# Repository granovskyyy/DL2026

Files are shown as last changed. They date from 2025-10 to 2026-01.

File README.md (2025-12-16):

# DL2026
Design Lab classes repository 
Project - IoT system based on ATMega328PB with all connectivity interfaces (I2C, SPI, UART etc) 
### FEATURES
The projects support various connectivity protocols such as: 
- UART
- I2C
- SPI
- 1-WIRE
- Outputs (7seg display)  
Software functions:
- UART connectivity and displaying counter of 7-seg display as well as data obtained from the sensors.
### HARDWARE
- ATMega328PB - microcontroller  
- BMP280 - Pressure sensor 
- DS18B20 – temperature probe 
- PL2303 - UART connectivity (in schematic is FT232RL used due to KiCad avaibality) 
- 3.3V voltage regulators 
- Capacitors (100n ceramic and 10uF electrolytic) 
- Resistors (4,7K to pullup, 220 for 7seg)
### SCHEMATIC


### PCB LAYOUT


### PCB MODEL


### PROJECT STRUCTURES  
- /datasheets/-  Components datasheets 
- schematics/  -  Schematics and PCB designs 
- I2C-BMP280/  -  I2C examples with BMP280 
- Final Project – complete DL code with support for all protocols 
- README.md

### SOFTWARE
- KiCad
- AVR Microchip Studio
#### COMPILATION 
avr-gcc -mmcu=atmega328pb -Os -o main.elf source_file.c
avr-objcopy -O ihex main.elf main.hex
#### FLASH
avrdude -c usbasp -p m328pb -U flash:w:main.hex

NOTE- you can compile code via Makefile

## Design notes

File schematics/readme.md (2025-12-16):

KICad is required to open schematics

This custom circuit was designed to measure properties of the fluids or gases using sensors, which could be obtained by connecting to the board via USB to uart connection or serial port.

Overall structure of the project is:
    -> datasheets folder - contains datasheets of all the elements used in the project.
    It is: 
        sensors: 
            BMP280, 
            BS18B20, 
        usb to uart: 
            PL2303GS USB to Full UART IC, 
        ATmega328PB Xplained Mini board.
    -> I2C-BMP280 folder - containing base library of communicating with BMP280 sensors via I2C interface, which was helpful in process of writing custom firmware for the project case.
    -> schematics folder - containing Electric Schematic and PCB design of the circuit.
    -> Final Project folder - containing final versions of the software used to read and display the data from sensors.

Firmware was written in C to maintain high readability, modularity and speed of the code, as well as future development of the project.

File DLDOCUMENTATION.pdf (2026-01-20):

# AGH UNIVERSITY OF CRACOW

# Project documentation - Design Lab 2025

### Authors: Karol Ożga, Tomasz Granowski, Dawid Chmielewski

## 1. Project description

This repository contains laboratory and final project work created during Design Lab classes. The project focuses on building an embedded IoT system using the ATMega328PB microcontroller and multiple communication interfaces.

## 2. Features:

The projects support various connectivity protocols such as:

- UART
- I2C
- SPI
- 1-WIRE
- Outputs (7seg display)

Software functions

- UART connectivity and displaying counter of 7-seg display as well as data obtained from the sensors.

## 3. Hardware:

- ATMega328PB - microcontroller
- BMP280 - Pressure sensor
- DS18B20 – temperature probe
- PL2303 - UART connectivity
- 3.3V voltage stabilizators
- Capacitors (100n ceramic and 10uF electrolyphic)
- Resistors (4,7K to pullup, 220 for 7seg)

## 4. Schematics:

Schematic:

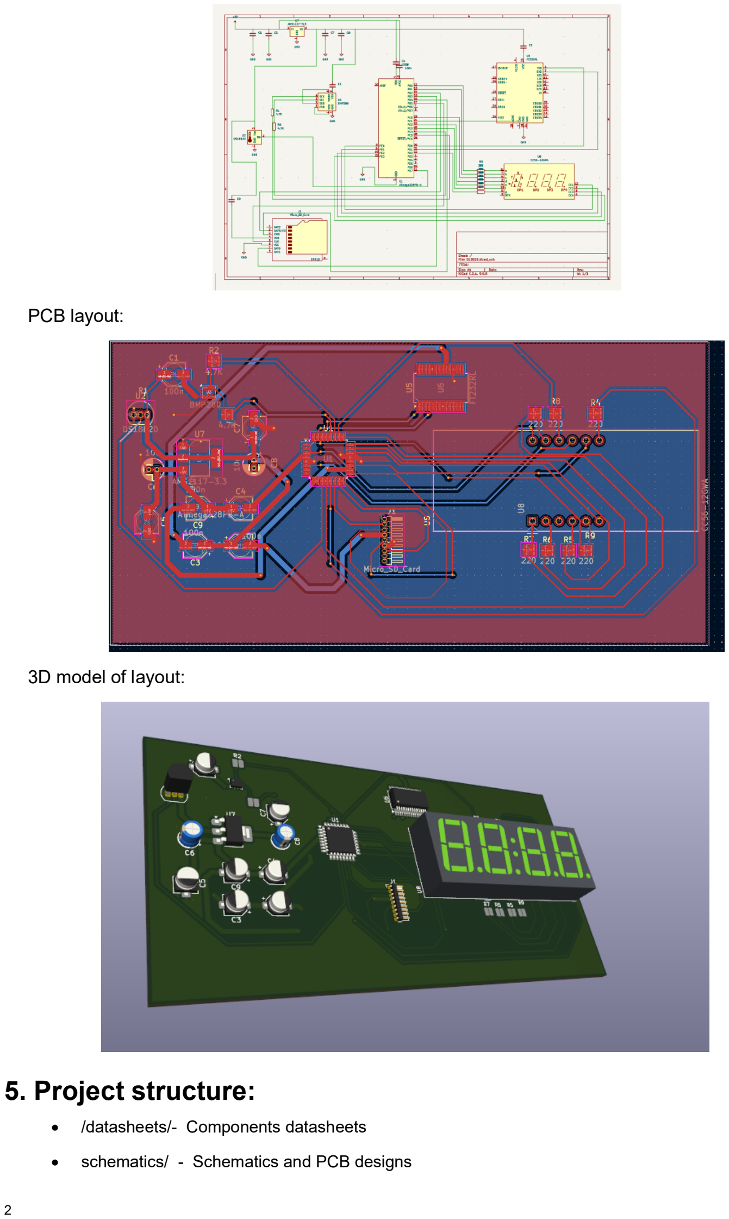
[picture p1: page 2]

2

PCB layout:

3D model of layout:

## 5. Project structure:

- /datasheets/- Components datasheets
- schematics/ - Schematics and PCB designs

3

- I2C-BMP280/ - I2C examples with BMP280
- Final Project – complete DL code with support for all protocols
- README.md

## 6. Requiremets

KiCad is required to open the schematics.

To build and run firmware you need:

- Software to program ATMega like AVR Microchip studio
- AVR_GCC toolchain
- “avr/io.h” , “util/delay.h” , “stdint.h” , “avr/interrupt.h” libraries
- If you want to compile project via terminal use these commands:

avr-gcc -mmcu=atmega328pb -Os -o main.elf source_file.c

avr-objcopy -O ihex main.elf main.hex

To flash use:

- avrdude -c usbasp -p m328pb -U flash:w:main.hex

Change settings/filenames if needed.

## 7. Connectivity with board

Data can be obtained via USB to Uart converter or via serial port. The circuit sends data which can be saved and later analyzed.

## 8. Possible Future improvements

Include saving data on SD card via SD card reader. Developing connectivity with the board via Bluetooth or Wi-Fi module. Creating a pc/mobile/web app displaying the measurements and options to save the data.

## 9. Links/sources

GitHub - https://github.com/granovskyyy/DL2026

## 10. Notes

This project is for educational purposes only.

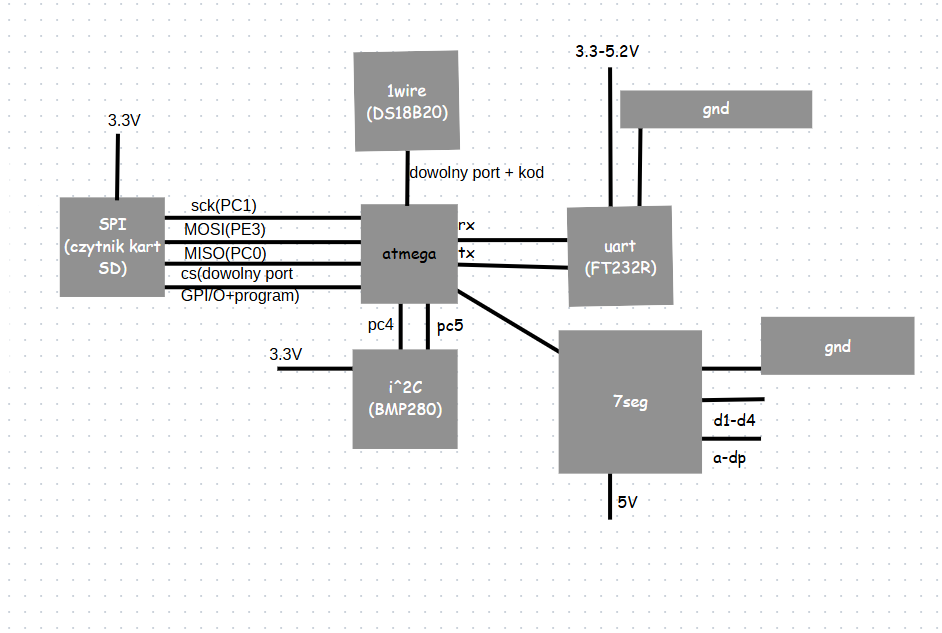
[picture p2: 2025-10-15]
schematics/Zrzut ekranu 2025-10-15 213119.png

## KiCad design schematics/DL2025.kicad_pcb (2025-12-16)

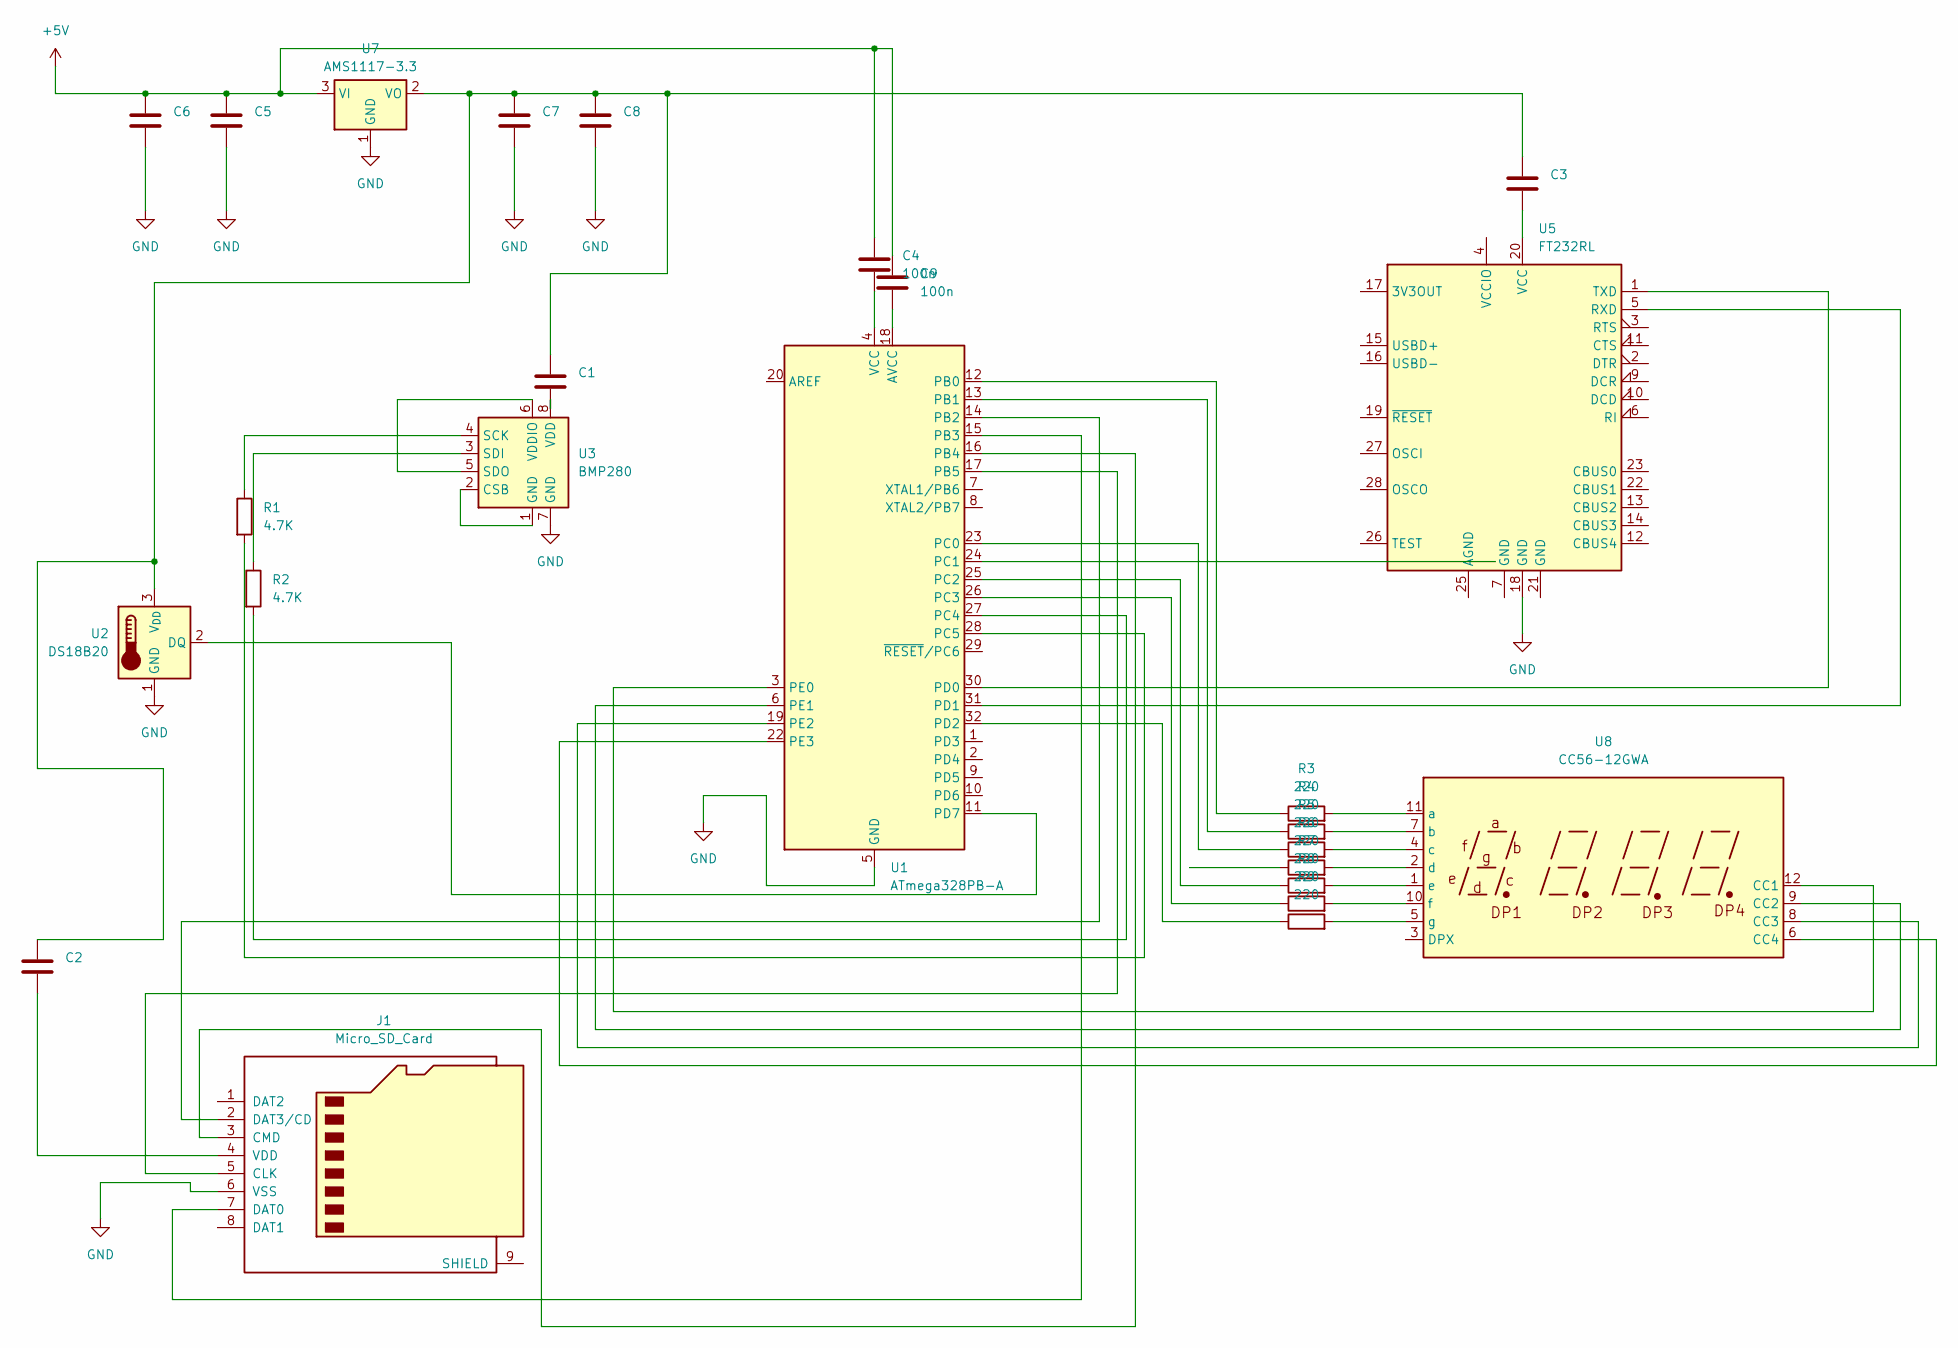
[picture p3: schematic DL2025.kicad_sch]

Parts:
C1, C2, C3, C4, C5, C7, C9: 100n; CP_Elec_4x3
C6, C8: 10u; CP_Radial_D4.0mm_P1.50mm
J1: Micro_SD_Card; PinHeader_1x09_P1.00mm_Horizontal
R1, R2: 4.7K; R_0508_1220Metric_Pad1.12x2.15mm_HandSolder
R3, R4, R5, R6, R7, R8, R9: 220; R_0508_1220Metric_Pad1.12x2.15mm_HandSolder
U1: ATmega328PB-A; TQFP-32_7x7mm_P0.8mm
U2: DS18B20; TO-92_Inline
U3: BMP280; Bosch_LGA-8_2x2.5mm_P0.65mm_ClockwisePinNumbering
U5: FT232RL; SSOP-28_5.3x10.2mm_P0.65mm
U7: AMS1117-3.3; SOT-223-3_TabPin2
U8: CC56-12GWA

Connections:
+5V: C4.1, C5.1, C6.1, C9.1, U7.3 (VI)
GND: C5.2, C6.2, C7.2, C8.2, J1.6 (VSS), U1.5 (GND), U1.21 (GND), U2.1 (GND), U3.7 (GND), U5.18 (GND), U7.1 (GND)
unnamed: J1.5 (CLK), U1.17 (PB5)
unnamed: J1.3 (CMD), U1.16 (PB4)
unnamed: J1.7 (DAT0), U1.15 (PB3)
unnamed: J1.2 (DAT3/CD), U1.14 (PB2)
unnamed: C2.2, J1.4 (VDD)
unnamed: C9.2, U1.18 (AVCC)
unnamed: R3.1, U1.12 (PB0)
unnamed: R4.1, U1.13 (PB1)
unnamed: R5.1, U1.23 (PC0)
unnamed: R6.1, U1.24 (PC1)
unnamed: R7.1, U1.25 (PC2)
unnamed: R8.1, U1.26 (PC3)
unnamed: R2.2, U1.27 (PC4)
unnamed: R1.2, U1.28 (PC5)
unnamed: U1.30 (PD0), U5.1 (TXD)
unnamed: U1.31 (PD1), U5.5 (RXD)
unnamed: R9.1, U1.32 (PD2)
unnamed: U1.11 (PD7), U2.2 (DQ)
unnamed: U1.3 (PE0), U8.12 (CC1)
unnamed: U1.6 (PE1), U8.9 (CC2)
unnamed: U1.19 (PE2), U8.8 (CC3)
unnamed: U1.22 (PE3), U8.6 (CC4)
unnamed: C4.2, U1.4 (VCC)
unnamed: C1.1, C2.1, C3.1, C7.1, C8.1, U2.3 (V_{DD}), U7.2 (VO)
unnamed: U3.1 (GND), U3.2 (CSB)
unnamed: R1.1, U3.4 (SCK)
unnamed: R2.1, U3.3 (SDI)
unnamed: U3.5 (SDO), U3.6 (VDDIO)
unnamed: C1.2, U3.8 (VDD)
unnamed: C3.2, U5.20 (VCC)
unnamed: R3.2, U8.11 (a)
unnamed: R4.2, U8.7 (b)
unnamed: R5.2, U8.4 (c)
unnamed: R6.2, U8.2 (d)
unnamed: R7.2, U8.1 (e)
unnamed: R8.2, U8.10 (f)
unnamed: R9.2, U8.5 (g)

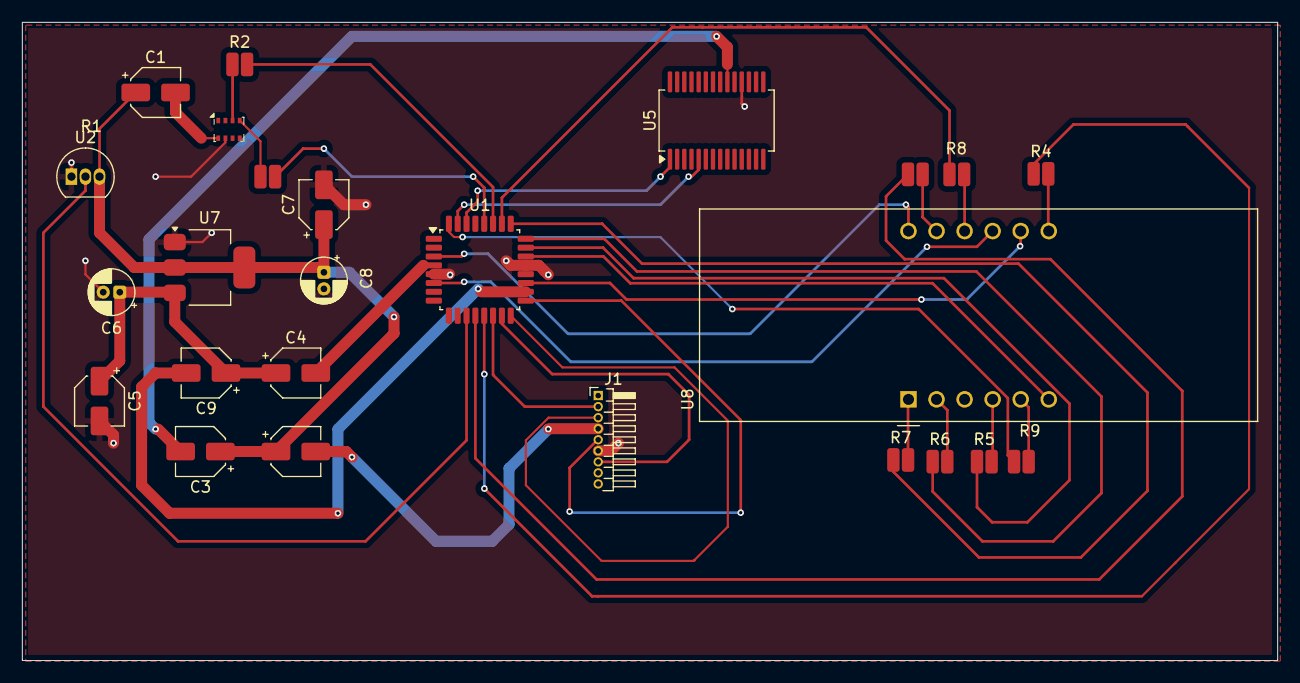
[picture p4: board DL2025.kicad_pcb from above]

Board: 2 copper layers, 113.7 x 57.8 mm, 25 parts (0 on the bottom side), 39 nets.

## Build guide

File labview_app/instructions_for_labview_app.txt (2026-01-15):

1. Na płytce wgrany jest nowy soft (nowy plik main.cpp) reszta taka sama.
2. Podłączasz płytkę przez usb, szukasz na którym COMx porcie jest.
3. W labview na front panelu wybierz VISA resource name -> COMx płytki
4. Aby zacząć odczytywać dane zakładka OPERATE -> RUN

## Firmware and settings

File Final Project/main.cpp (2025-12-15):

#define F_CPU 16000000UL

#include <avr/io.h>
#include <util/delay.h>
#include <stdint.h>
#include <avr/interrupt.h>
#include "uart.h"
#include "I2C.h"
#include "BMP280.h"
#include "DS18B20.h"
#include "7SEG.h"
#include "button.h"


int main(void)
{
	// output LEDs
	DDRB |= (1 << PB2) | (1 << PB3) | (1 << PB4);
	PORTB &= ~((1 << PB2) | (1 << PB3) | (1 << PB4)); // turn off all LEDs

	uart_init(9600);
	i2c_init();
	display_io_init();
	display_timer_init();
	button_init();
	ds18b20_io_init();

	sei(); // enable global interrupts (for display timer)

	uart_puts("\r\nBMP280 + DS18B20 temp + pressure with 7-seg display\r\n");
	bmp280_init();

	int32_t adc_T = 0, adc_P = 0;
	int32_t temp_c_x100 = 0;
	uint32_t press_pa = 0, press_hpa = 0;

	int32_t sonda_temp_c_x100 = 0;

	// 7SEG_mode:
	// 0 -> BMP280 temperature
	// 1 -> BMP280 pressure
	// 2 -> DS18B20 temperature (sonda)
	
	uint8_t SEG_mode = 0;

	// Initialize 7SEG with 0.0�C (BMP mode)
	update_7SEG_temperature(0);

	uint16_t ms_counter = 0;        // for 1 s intervals
	uint8_t SEG_second_counter = 0; // for 2 s LCD update period

	while (1)
	{
		// base tick: 10 ms
		_delay_ms(10);
		ms_counter += 10;

		// button toggle: cycle through 3 display modes
		if (button_was_pressed())
		{
			SEG_mode = (SEG_mode + 1) % 3;

			if (SEG_mode == 0)
			update_7SEG_temperature(temp_c_x100);
			else if (SEG_mode == 1)
			update_7SEG_pressure(press_hpa);
			else
			update_7SEG_sonda_temperature(sonda_temp_c_x100);
			
			update_mode_leds(SEG_mode);
		}

		// every ~1 s: read sensors + print via UART
		if (ms_counter >= 1000)
		{
			ms_counter = 0;

			// BMP280 read
			bmp280_read_raw(&adc_T, &adc_P);
			temp_c_x100 = bmp280_compensate_T(adc_T);
			press_pa    = bmp280_compensate_P(adc_P);
			press_hpa   = press_pa / 100U;

			// DS18B20 read
			sonda_temp_c_x100 = ds18b20_get_temperature_c_x100();

			// Line 1: BMP280
			uart_puts("T = ");
			int32_t t_print = temp_c_x100;
			if (t_print < 0)
			{
				uart_putc('-');
				t_print = -t_print;
			}
			uart_print_uint32((uint32_t)(t_print / 100));
			uart_putc('.');
			uint8_t frac = (uint8_t)(t_print % 100);
			if (frac < 10) uart_putc('0');
			uart_print_uint32(frac);
			uart_puts(" C, P = ");
			uart_print_uint32(press_hpa);
			uart_puts(" hPa\r\n");

			// Line 2: DS18B20
			uart_puts("Temp. from sonda : ");
			int32_t s_print = sonda_temp_c_x100;
			if (s_print < 0)
			{
				uart_putc('-');
				s_print = -s_print;
			}
			uart_print_uint32((uint32_t)(s_print / 100));
			uart_putc('.');
			uint8_t s_frac = (uint8_t)((s_print / 10) % 10);  // 1 decimal place
			uart_print_uint32(s_frac);
			uart_puts(" C\r\n\r\n");

			// 7SEG update every ~2 s
			SEG_second_counter++;
			if (SEG_second_counter >= 2)
			{
				SEG_second_counter = 0;

				if (SEG_mode == 0)
				update_7SEG_temperature(temp_c_x100);
				else if (SEG_mode == 1)
				update_7SEG_pressure(press_hpa);
				else
				update_7SEG_sonda_temperature(sonda_temp_c_x100);
				update_mode_leds(SEG_mode);
			}
		}
	}
}

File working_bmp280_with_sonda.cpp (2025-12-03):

#define F_CPU 16000000UL

#include <avr/io.h>
#include <util/delay.h>
#include <stdint.h>
#include <avr/interrupt.h>

// ---------- UART (USART0) ----------

void uart_init(uint32_t baud)
{
	uint16_t ubrr = (F_CPU / (16UL * baud)) - 1;
	UBRR0H = (uint8_t)(ubrr >> 8);
	UBRR0L = (uint8_t)ubrr;
	UCSR0A = 0;
	UCSR0B = (1 << RXEN0) | (1 << TXEN0);
	UCSR0C = (1 << UCSZ01) | (1 << UCSZ00); // 8N1
}

void uart_putc(char c)
{
	while (!(UCSR0A & (1 << UDRE0))) {;}
	UDR0 = c;
}

void uart_puts(const char *s)
{
	while (*s)
	{
		if (*s == '\n')
		uart_putc('\r');  // CRLF
		uart_putc(*s++);
	}
}

void uart_print_uint32(uint32_t v)
{
	char buf[11];
	uint8_t i = 0;

	if (v == 0)
	{
		uart_putc('0');
		return;
	}

	while (v > 0 && i < sizeof(buf))
	{
		uint8_t digit = v % 10;
		buf[i++] = '0' + digit;
		v /= 10;
	}

	while (i > 0)
	{
		uart_putc(buf[--i]);
	}
}

// ---------- I2C (TWI0) low level ----------

#ifdef __AVR_ATmega328PB__
#ifndef TWSR
#define TWSR   TWSR0
#endif
#ifndef TWBR
#define TWBR   TWBR0
#endif
#ifndef TWAR
#define TWAR   TWAR0
#endif
#ifndef TWDR
#define TWDR   TWDR0
#endif
#ifndef TWCR
#define TWCR   TWCR0
#endif
#ifndef TWINT
#define TWINT  TWINT0
#endif
#ifndef TWEA
#define TWEA   TWEA0
#endif
#ifndef TWSTA
#define TWSTA  TWSTA0
#endif
#ifndef TWSTO
#define TWSTO  TWSTO0
#endif
#ifndef TWEN
#define TWEN   TWEN0
#endif
#ifndef TWPS0
#ifdef TWPS00
#define TWPS0  TWPS00
#endif
#endif
#ifndef TWPS1
#ifdef TWPS01
#define TWPS1  TWPS01
#endif
#endif
#endif

#define TWI_READ  1
#define TWI_WRITE 0

void i2c_init(void)
{
	// Prescaler = 1
	TWSR &= ~((1 << TWPS0) | (1 << TWPS1));
	// 100 kHz @ 16 MHz: TWBR = 72
	TWBR = 72;
	// Enable TWI
	TWCR = (1 << TWEN);
}

static uint8_t i2c_start(uint8_t address_rw)
{
	// Send START
	TWCR = (1 << TWINT) | (1 << TWSTA) | (1 << TWEN);
	while (!(TWCR & (1 << TWINT))) {;}

	// Send SLA+R/W
	TWDR = address_rw;
	TWCR = (1 << TWINT) | (1 << TWEN);
	while (!(TWCR & (1 << TWINT))) {;}

	return 0;
}

static void i2c_stop(void)
{
	TWCR = (1 << TWINT) | (1 << TWEN) | (1 << TWSTO);
}

static uint8_t i2c_write(uint8_t data)
{
	TWDR = data;
	TWCR = (1 << TWINT) | (1 << TWEN);
	while (!(TWCR & (1 << TWINT))) {;}
	return 0;
}

static uint8_t i2c_read_ack(void)
{
	TWCR = (1 << TWINT) | (1 << TWEN) | (1 << TWEA);
	while (!(TWCR & (1 << TWINT))) {;}
	return TWDR;
}

static uint8_t i2c_read_nack(void)
{
	TWCR = (1 << TWINT) | (1 << TWEN);
	while (!(TWCR & (1 << TWINT))) {;}
	return TWDR;
}

void i2c_write_reg(uint8_t dev_addr7, uint8_t reg, uint8_t value)
{
	i2c_start((dev_addr7 << 1) | TWI_WRITE);
	i2c_write(reg);
	i2c_write(value);
	i2c_stop();
}

uint8_t i2c_read_reg(uint8_t dev_addr7, uint8_t reg)
{
	uint8_t val;
	i2c_start((dev_addr7 << 1) | TWI_WRITE);
	i2c_write(reg);
	i2c_start((dev_addr7 << 1) | TWI_READ);
	val = i2c_read_nack();
	i2c_stop();
	return val;
}

void i2c_read_multi(uint8_t dev_addr7, uint8_t reg, uint8_t *buf, uint8_t len)
{
	i2c_start((dev_addr7 << 1) | TWI_WRITE);
	i2c_write(reg);
	i2c_start((dev_addr7 << 1) | TWI_READ);

	for (uint8_t i = 0; i < len; i++)
	{
		if (i < (len - 1))
		buf[i] = i2c_read_ack();
		else
		buf[i] = i2c_read_nack();
	}

	i2c_stop();
}

// ---------- BMP280 driver (minimal) ----------

#define BMP280_I2C_ADDR 0x76  // if it doesn't work, try 0x77

// Registers
#define BMP280_REG_CHIPID      0xD0
#define BMP280_REG_RESET       0xE0
#define BMP280_REG_STATUS      0xF3
#define BMP280_REG_CTRL_MEAS   0xF4
#define BMP280_REG_CONFIG      0xF5
#define BMP280_REG_PRESS_MSB   0xF7
#define BMP280_REG_CALIB_START 0x88

typedef struct
{
	uint16_t dig_T1;
	int16_t  dig_T2;
	int16_t  dig_T3;
	uint16_t dig_P1;
	int16_t  dig_P2;
	int16_t  dig_P3;
	int16_t  dig_P4;
	int16_t  dig_P5;
	int16_t  dig_P6;
	int16_t  dig_P7;
	int16_t  dig_P8;
	int16_t  dig_P9;
} bmp280_calib_t;

bmp280_calib_t calib;
int32_t t_fine;

void bmp280_read_calibration(void)
{
	uint8_t data[24];
	i2c_read_multi(BMP280_I2C_ADDR, BMP280_REG_CALIB_START, data, 24);

	calib.dig_T1 = (uint16_t)(data[1] << 8 | data[0]);
	calib.dig_T2 = (int16_t)(data[3] << 8 | data[2]);
	calib.dig_T3 = (int16_t)(data[5] << 8 | data[4]);
	calib.dig_P1 = (uint16_t)(data[7] << 8 | data[6]);
	calib.dig_P2 = (int16_t)(data[9] << 8 | data[8]);
	calib.dig_P3 = (int16_t)(data[11] << 8 | data[10]);
	calib.dig_P4 = (int16_t)(data[13] << 8 | data[12]);
	calib.dig_P5 = (int16_t)(data[15] << 8 | data[14]);
	calib.dig_P6 = (int16_t)(data[17] << 8 | data[16]);
	calib.dig_P7 = (int16_t)(data[19] << 8 | data[18]);
	calib.dig_P8 = (int16_t)(data[21] << 8 | data[20]);
	calib.dig_P9 = (int16_t)(data[23] << 8 | data[22]);
}

// temperature in 0.01 °C
int32_t bmp280_compensate_T(int32_t adc_T)
{
	int32_t var1, var2, T;
	var1 = ((((adc_T >> 3) - ((int32_t)calib.dig_T1 << 1))) *
	((int32_t)calib.dig_T2)) >> 11;
	var2 = (((((adc_T >> 4) - ((int32_t)calib.dig_T1)) *
	((adc_T >> 4) - ((int32_t)calib.dig_T1))) >> 12) *
	((int32_t)calib.dig_T3)) >> 14;

	t_fine = var1 + var2;
	T = (t_fine * 5 + 128) >> 8;   // 0.01 °C
	return T;
}

// pressure in Pa (unsigned)
uint32_t bmp280_compensate_P(int32_t adc_P)
{
	double var1, var2, p;

	var1 = ((double)t_fine / 2.0) - 64000.0;
	var2 = var1 * var1 * ((double)calib.dig_P6) / 32768.0;
	var2 = var2 + var1 * ((double)calib.dig_P5) * 2.0;
	var2 = (var2 / 4.0) + (((double)calib.dig_P4) * 65536.0);
	var1 = (((double)calib.dig_P3) * var1 * var1 / 524288.0 +
	((double)calib.dig_P2) * var1) / 524288.0;
	var1 = (1.0 + var1 / 32768.0) * (double)calib.dig_P1;

	if (var1 == 0.0)
	return 0;

	p = 1048576.0 - (double)adc_P;
	p = (p - (var2 / 4096.0)) * 6250.0 / var1;
	var1 = ((double)calib.dig_P9) * p * p / 2147483648.0;
	var2 = p * ((double)calib.dig_P8) / 32768.0;
	p = p + (var1 + var2 + ((double)calib.dig_P7)) / 16.0;

	if (p < 0.0)
	p = 0.0;

	return (uint32_t)(p + 0.5);
}

void bmp280_init(void)
{
	// Soft reset
	i2c_write_reg(BMP280_I2C_ADDR, BMP280_REG_RESET, 0xB6);
	_delay_ms(5);

	// Read chip ID
	uint8_t id = i2c_read_reg(BMP280_I2C_ADDR, BMP280_REG_CHIPID);
	uart_puts("BMP280 ID = 0x");
	const char hex[] = "0123456789ABCDEF";
	uart_putc(hex[(id >> 4) & 0x0F]);
	uart_putc(hex[id & 0x0F]);
	uart_puts("\r\n");

	// Read calibration
	bmp280_read_calibration();

	// ctrl_meas: temp x1, press x1, normal mode => 0x27
	i2c_write_reg(BMP280_I2C_ADDR, BMP280_REG_CTRL_MEAS, 0x27);
	// config: standby 500 ms, filter off => 0xA0
	i2c_write_reg(BMP280_I2C_ADDR, BMP280_REG_CONFIG, 0xA0);
}

void bmp280_read_raw(int32_t *adc_T, int32_t *adc_P)
{
	uint8_t buf[6];
	i2c_read_multi(BMP280_I2C_ADDR, BMP280_REG_PRESS_MSB, buf, 6);

	int32_t adc_P_local = ((int32_t)buf[0] << 12) | ((int32_t)buf[1] << 4) | (buf[2] >> 4);
	int32_t adc_T_local = ((int32_t)buf[3] << 12) | ((int32_t)buf[4] << 4) | (buf[5] >> 4);

	*adc_P = adc_P_local;
	*adc_T = adc_T_local;
}

// ===== LCD / 7-seg display code (START) =====
// Wiring:
//   a -> PB0
//   b -> PB1
//   c -> PC0
//   d -> PC1
//   e -> PC2
//   f -> PC3
//   g -> PD2
//   DP -> PD3
//   Digit0..3 (common anodes, active LOW) -> PE0..PE3
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

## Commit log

2025-10-15 block diagram of circuit
2025-11-04 kicad scheme of circuit
    [DL2025.kicad_sch]
2025-11-04 Update readme with KICad requirement
    Added requirement for KICad to open schematics.
2025-11-17 Add UART functionality and display digit control
    Implement UART communication and 7-segment display control
2025-11-19 PCB board
    [DL2025.kicad_pcb]
2025-12-02 Updated schematics, just one AMS1117
    [DL2025.kicad_sch]
2025-12-02 Added new schematics: atmega328pb, uart
2025-12-02 Updated schematics, added LCD_DP -> PC3 connection
    [DL2025.kicad_sch]
2025-12-03 updated PCB schematic
    [DL2025.kicad_pcb]
2025-12-03 updated schematic, added capacitors
    [DL2025.kicad_sch]
2025-12-16 Update README with PCB layout image
    Added PCB layout image to README.
2025-12-16 Enhance README with schematic and PCB details
    Added schematic, PCB layout, and PCB model sections with images.
2025-12-16 updated schematics
    [DL2025.kicad_pcb, DL2025.kicad_sch]
